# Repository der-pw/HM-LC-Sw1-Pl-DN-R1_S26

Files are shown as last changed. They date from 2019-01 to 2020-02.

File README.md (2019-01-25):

# HM-LC-Sw1-Pl-DN-R1_S26          

### Dieses Projekt beschreibt den Umbau eines Sonoff S26 Zwischenstecker zum HM-LC-Sw1-Pl-DN-R1_S26  
... und basiert auf der hervorragenden Arbeit von [pa-pa](https://github.com/pa-pa/AskSinPP), [Jérôme](https://github.com/jp112sdl/Beispiel_AskSinPP), sowie meiner Inspirationsquelle [stan23](https://github.com/stan23) mit seinem Umbau OBI-Wifi-Stecker zu [HM-LC-Sw1-Pl-DN-R1_OBI](https://github.com/stan23/HM-LC-Sw1-Pl-DN-R1_OBI).

Weitere Informationen gibt es im [Wiki](https://github.com/der-pw/HM-LC-Sw1-Pl-DN-R1_S26/wiki).

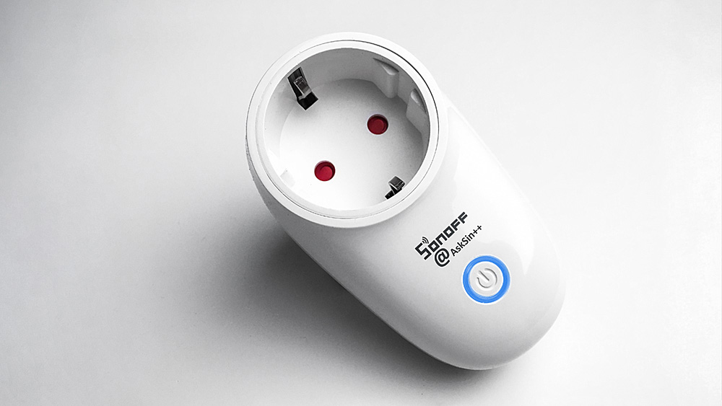
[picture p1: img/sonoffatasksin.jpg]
Rückansicht HM-LC-Sw1-Pl-DN-R1_S26




Dieses Werk ist lizenziert unter einer [Creative Commons Namensnennung - Nicht-kommerziell - Weitergabe unter gleichen Bedingungen 4.0 International Lizenz](http://creativecommons.org/licenses/by-nc-sa/4.0/).

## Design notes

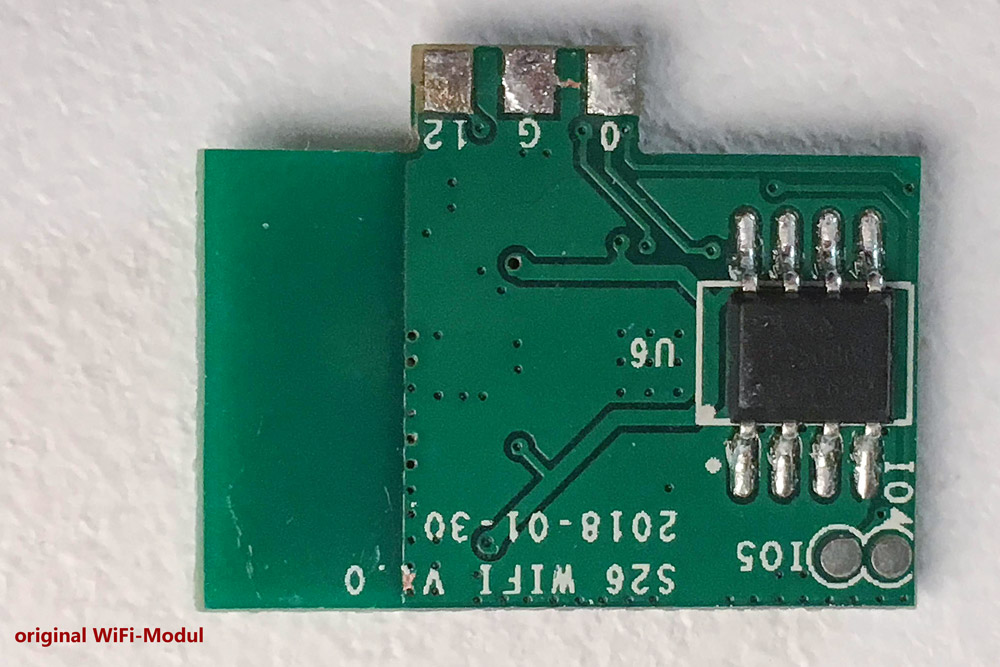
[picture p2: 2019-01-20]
img/S26_wifi_back.jpg

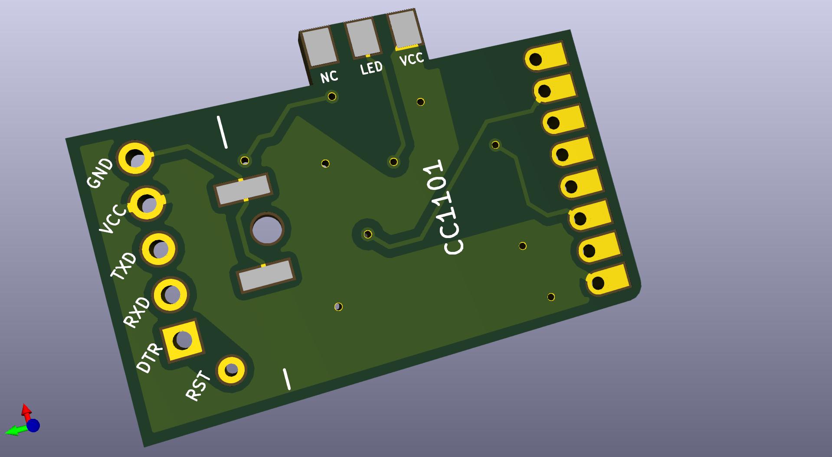
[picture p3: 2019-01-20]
img/PCB_3D_front.jpg

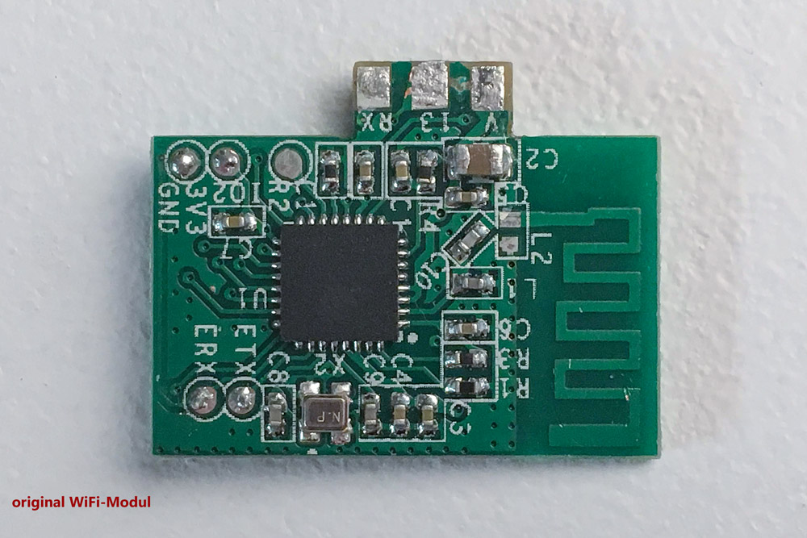
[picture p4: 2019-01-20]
img/S26_wifi_front.jpg

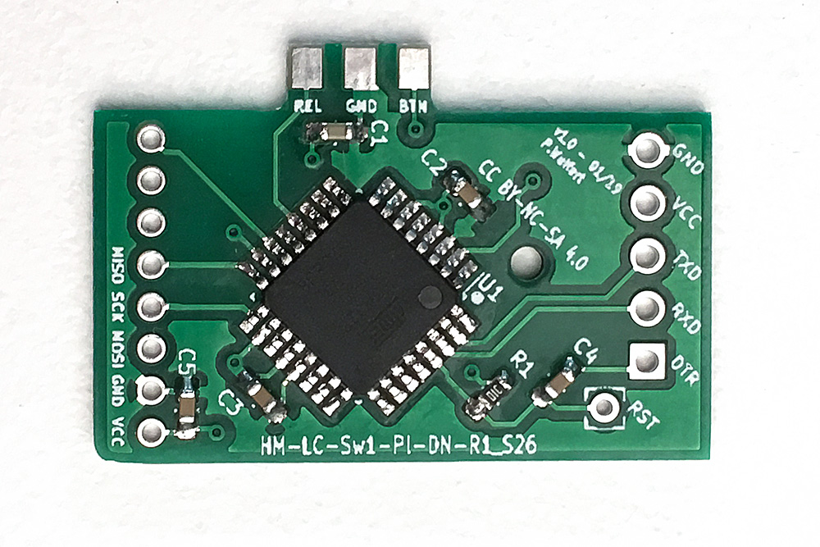
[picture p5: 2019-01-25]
img/S26_HM_back.jpg

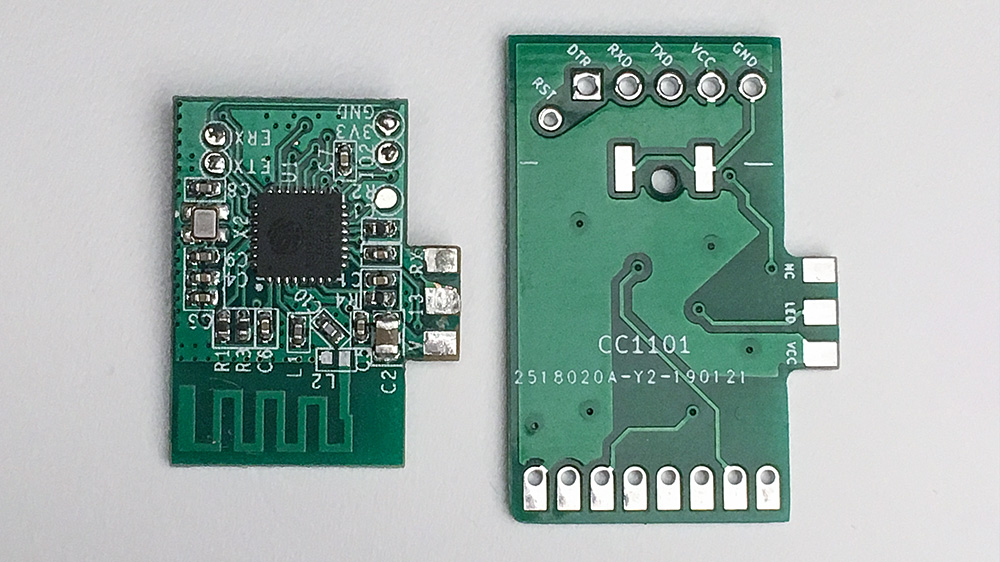
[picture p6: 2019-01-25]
img/vergl_f.jpg

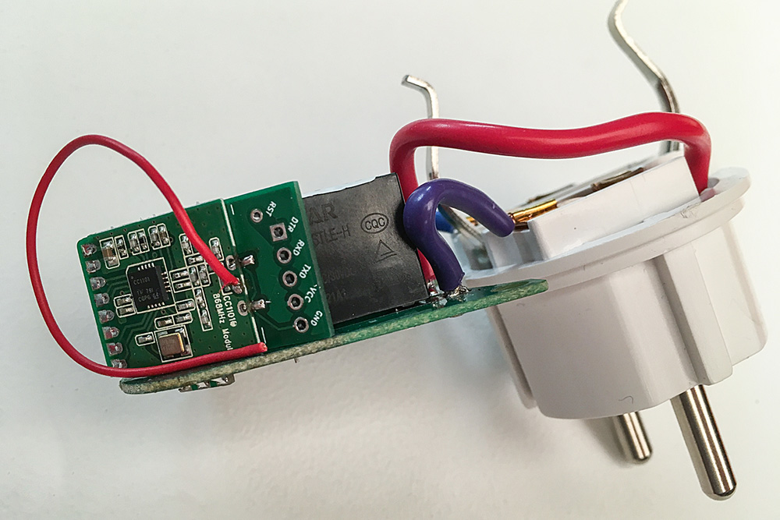
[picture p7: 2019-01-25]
img/S26_HM_eingeb_b.jpg

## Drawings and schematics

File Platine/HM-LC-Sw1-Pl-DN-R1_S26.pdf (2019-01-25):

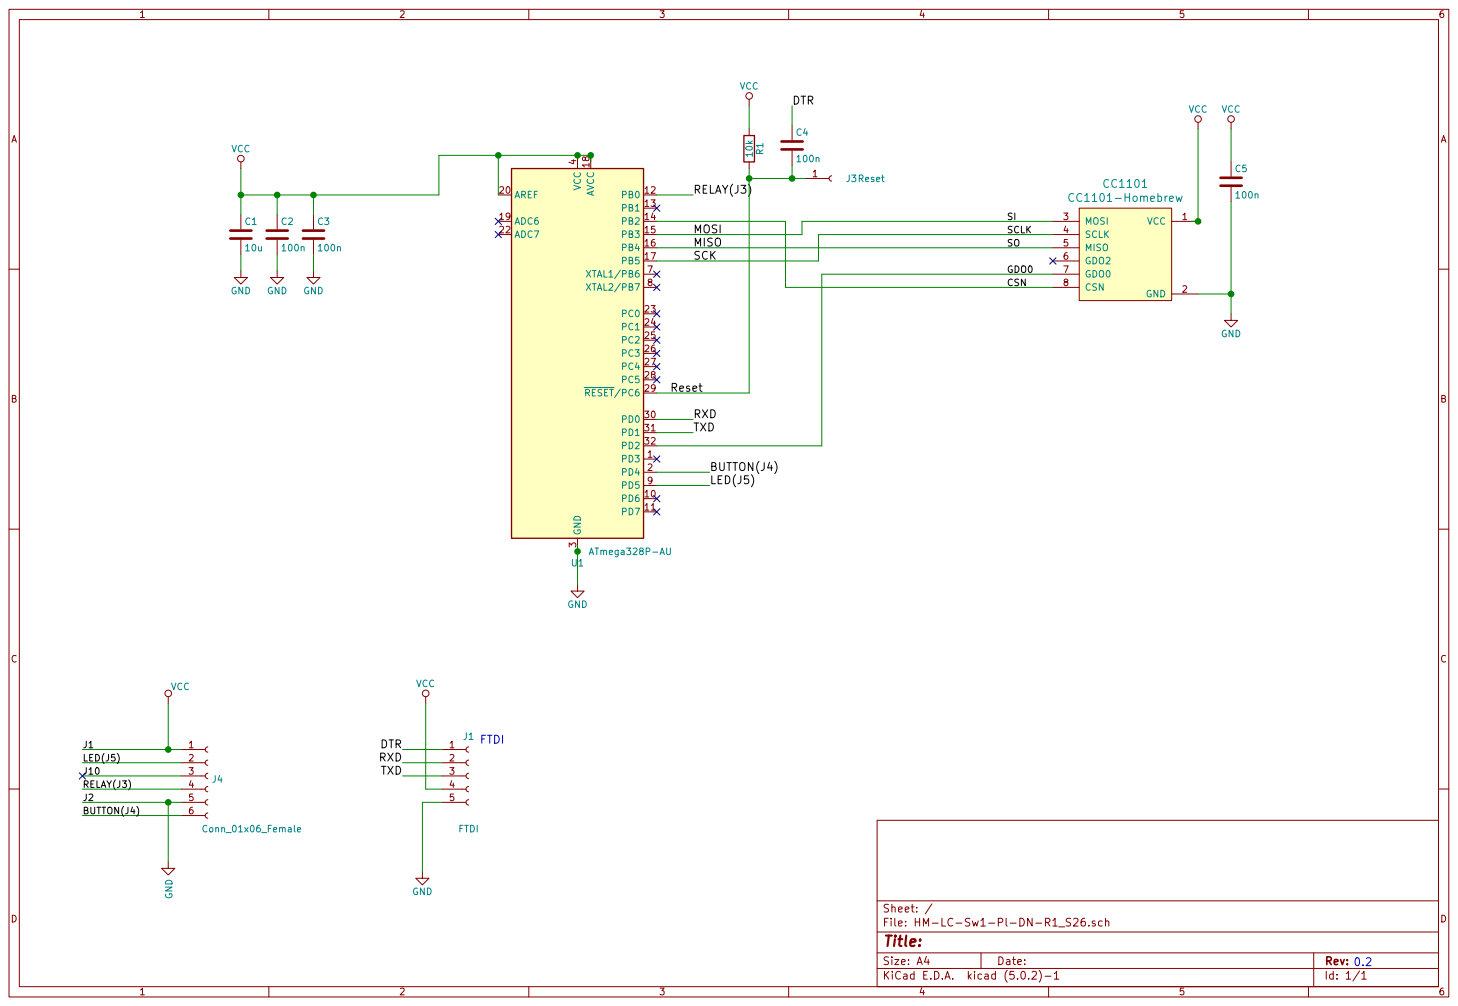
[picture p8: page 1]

MISO
SCK | CSN GDO0 SO

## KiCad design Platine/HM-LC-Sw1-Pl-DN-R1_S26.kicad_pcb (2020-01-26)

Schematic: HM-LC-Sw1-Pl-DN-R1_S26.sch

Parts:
C1: 10u; C_0603_1608Metric_Pad1.05x0.95mm_HandSolder
C2, C3, C4, C5: 100n; C_0603_1608Metric_Pad1.05x0.95mm_HandSolder
CC1101: CC1101-Homebrew; CC1101
J1: FTDI; PinHeader_1x05_P2.54mm_Vertical
J3: Reset; Pin_D0.7mm_L6.5mm_W1.8mm_FlatFork
J4: Conn_01x06_Female; Sonoff_S26_Connector
R1: 10k; C_0603_1608Metric_Pad1.05x0.95mm_HandSolder
U1: ATmega328P-AU; TQFP-32_7x7mm_P0.8mm

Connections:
/BUTTON(J4): J4.6, U1.2 (PD4)
/CSN: CC1101.8 (CSN), U1.14 (PB2)
/DTR: C4.1, J1.1
/GDO0: CC1101.7 (GDO0), U1.32 (PD2)
/J10: J4.3
/LED(J5): J4.2, U1.9 (PD5)
/MISO: CC1101.5 (MISO), U1.16 (PB4)
/MOSI: CC1101.3 (MOSI), U1.15 (PB3)
/RELAY(J3): J4.4, U1.12 (PB0)
/RXD: J1.3, U1.30 (PD0)
/Reset: C4.2, J3.1, R1.2, U1.29 (~RESET~/PC6)
/SCLK: CC1101.4 (SCLK), U1.17 (PB5)
/TXD: J1.2, U1.31 (PD1)
GND: C1.2, C2.2, C3.2, C5.2, CC1101.2 (GND), J1.5, J1.6, J4.5, U1.3 (GND), U1.5 (GND), U1.21 (GND); also elsewhere on the board
VCC: C1.1, C2.1, C3.1, C5.1, CC1101.1 (VCC), J1.4, J4.1, R1.1, U1.4 (VCC), U1.6 (VCC), U1.18 (AVCC), U1.20 (AREF)

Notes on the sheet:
FTDI
0.2

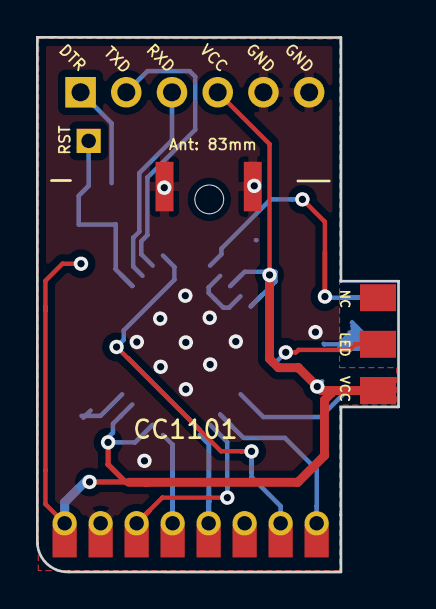
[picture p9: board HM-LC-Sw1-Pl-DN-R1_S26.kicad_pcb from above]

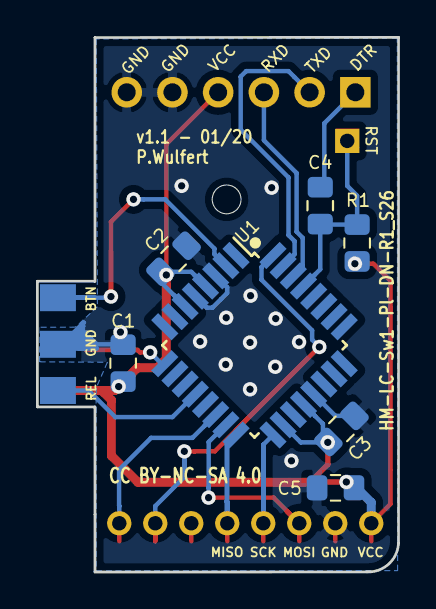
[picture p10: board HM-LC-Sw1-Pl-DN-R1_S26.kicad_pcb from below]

Board: 2 copper layers, 20.1 x 29.7 mm, 12 parts (9 on the bottom side), 14 nets.

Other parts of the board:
U2: CC1101-; CC1101_SMD_Kopfkontakte

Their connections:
GND: U2.10, U2.11; also elsewhere on the board

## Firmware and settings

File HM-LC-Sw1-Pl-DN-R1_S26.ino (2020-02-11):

//- -----------------------------------------------------------------------------------------------------------------------
// AskSin++
// 2016-10-31 papa Creative Commons - http://creativecommons.org/licenses/by-nc-sa/3.0/de/
// 2018-09-12 jp112sdl Creative Commons - http://creativecommons.org/licenses/by-nc-sa/3.0/de/
//- -----------------------------------------------------------------------------------------------------------------------

// #define NDEBUG  

// define this to read the device id, serial and device type from bootloader section
// #define USE_OTA_BOOTLOADER

// number of relays by defining the device
#define EI_NOTEXTERNAL
#include <EnableInterrupt.h>
#include <AskSinPP.h>
#include <LowPower.h>

#include <Switch.h>

//pins are fixed by the pcb layout
#define LED_PIN           5  // low-active
#define CONFIG_BUTTON_PIN 4
#define RELAY1_PIN        8

// number of available peers per channel
#define PEERS_PER_CHANNEL 8

// all library classes are placed in the namespace 'as'
using namespace as;

// define all device properties
const struct DeviceInfo PROGMEM devinfo = {
  {0x01, 0xd8, 0x01},     // Device ID
  "S26PLG0001",           // Device Serial
  {0x00,0xd8},            // Device Model
  0x26,                   // Firmware Version
  as::DeviceType::Switch, // Device Type
  {0x01, 0x00}            // Info Bytes
};

/**
   Configure the used hardware
*/
typedef AvrSPI<10, 11, 12, 13> RadioSPI;
typedef AskSin<StatusLed<LED_PIN>, NoBattery, Radio<RadioSPI, 2> > Hal;

// setup the device with channel type and number of channels
typedef MultiChannelDevice<Hal, SwitchChannel<Hal, PEERS_PER_CHANNEL, List0>, 1> SwitchType;

Hal hal;
SwitchType sdev(devinfo, 0x20);

ConfigToggleButton<SwitchType> cfgBtn(sdev);

void initPeerings (bool first) {
  // create internal peerings - CCU2 needs this
  if ( first == true ) {
    HMID devid;
    sdev.getDeviceID(devid);
    for ( uint8_t i = 1; i <= sdev.channels(); ++i ) {
      Peer ipeer(devid, i);
      sdev.channel(i).peer(ipeer);
    }
  }
}

void setup () {
  DINIT(57600, ASKSIN_PLUS_PLUS_IDENTIFIER);
  bool first = sdev.init(hal);
  sdev.channel(1).init(RELAY1_PIN, false);
  
  buttonISR(cfgBtn, CONFIG_BUTTON_PIN);
  
  sdev.channels(1);
  initPeerings(first);
  sdev.initDone();
  sdev.led().invert(true);  // inverts the LED signal, otherwise the blue LED lights up permanently and flashes only by status requests
}

void loop() {
  bool worked = hal.runready();
  bool poll = sdev.pollRadio();
  if ( worked == false && poll == false ) {
    hal.activity.savePower<Idle<> >(hal);
  }
}

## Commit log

2019-01-25 evaluation finished
    [HM-LC-Sw1-Pl-DN-R1_S26-B.Cu.gbr, HM-LC-Sw1-Pl-DN-R1_S26-B.Mask.gbr, HM-LC-Sw1-Pl-DN-R1_S26-B.Paste.gbr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]
2019-01-25 change Device Model
2020-01-26 update to V1.1
    [HM-LC-Sw1-Pl-DN-R1_S26-B.Cu.gbr, HM-LC-Sw1-Pl-DN-R1_S26-B.Mask.gbr, HM-LC-Sw1-Pl-DN-R1_S26-B.Paste.gbr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]

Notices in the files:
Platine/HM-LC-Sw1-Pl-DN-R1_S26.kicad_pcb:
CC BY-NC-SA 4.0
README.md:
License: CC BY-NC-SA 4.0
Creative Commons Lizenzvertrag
